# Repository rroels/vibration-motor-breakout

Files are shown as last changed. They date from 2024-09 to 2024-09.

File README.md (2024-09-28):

# 2-in-1 Vibration Motor Breakout Board

> [!WARNING]
> The information and material (code, designs, files, ...) are provided "AS IS". We make no representation or warranty of any kind, express or implied, regarding the accuracy, adequacy, validity, reliability, availability, or completeness of any information or material. Use this at your own risk.

> [!WARNING]
> At the time of writing this PCB has not even been produced yet, and as such, it has not even been tested yet! Once it has been properly tested, I will confirm that everything works as expected.

## Introduction

This is a breakout board for small vibration motors, such as those used in (smart)watches.

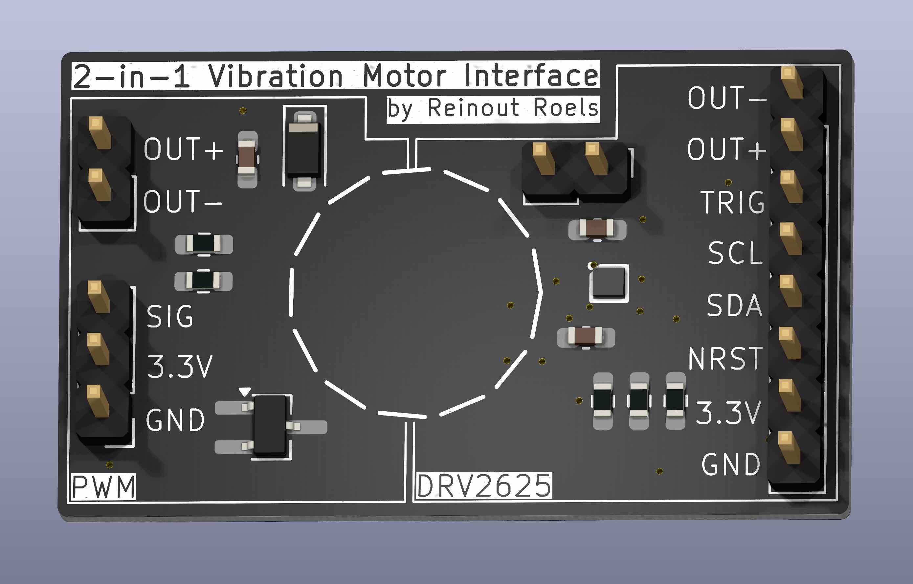
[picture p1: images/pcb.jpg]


It is 2-in-1, because it provides two ways to interface with the motor:

* via PWM
* via the Texas Instruments DRV2625 Haptic Driver IC

## Change Log

* v1.0
  * Initial design 

## Design Considerations

* NRST is not connected to the chip, as I was not able to route the NRST pin out of the tiny BGA footprint. This is however an optional feature anyway. 

## Schematics 

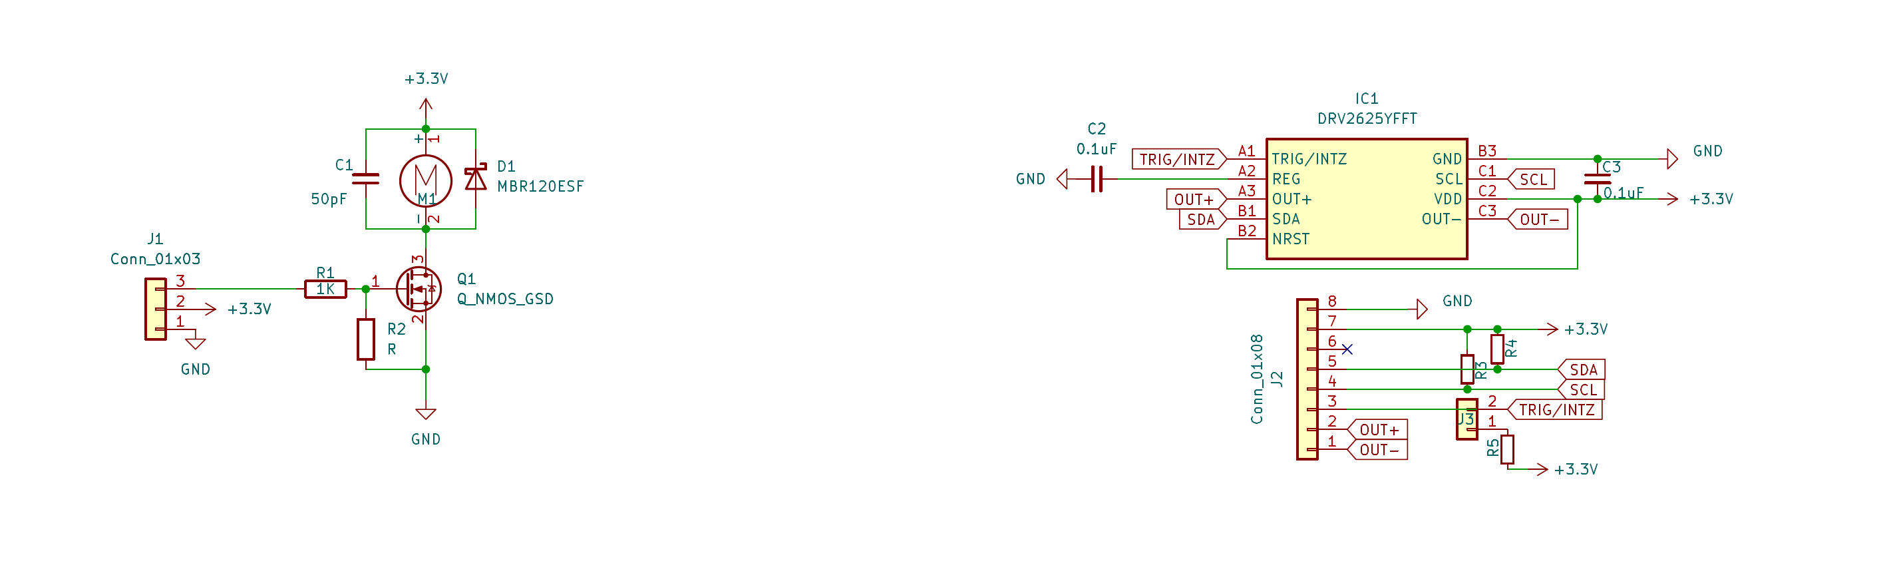
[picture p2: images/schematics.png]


## How to Obtain the Physical PCB



The Gerber file is in this repository (`kicad/gerber/vibration-motor.zip`). Simply upload this file a PCB manufacturer of your choice (JLPCB, PCBWay, ...), and you they will make it for you for as low as \$5 for 5 pieces (with the cheapest shipping option, which can take a few weeks).

For JLCPCB, select the order number option where they will replace "JLCJLCJLCJLC" on the board with the actual order number.

> [!WARNING]
> Note that will still have to solder the components onto the PCB yourself!

## How to Edit Design

Everything you need to edit this design in KiCad 8 is included in the repository.

However, this project uses symbols, footprints and 3D models from [Component Search Engine](https://componentsearchengine.com/). Their license allows us to do pretty much whatever we want with them, except redistributing them. For this reason I can't include them in this repository.

If you would like to edit the design yourself, you will need to download the following component libraries from [https://componentsearchengine.com/](https://componentsearchengine.com/) (it's free!):

* [https://componentsearchengine.com/part-view/DRV2625YFFT/Texas%20Instruments](https://componentsearchengine.com/part-view/DRV2625YFFT/Texas%20Instruments)

From the downloaded zip files, move the content of the `KiCad` and `3D` subfolders into the project structure, so that the end-result looks like this:

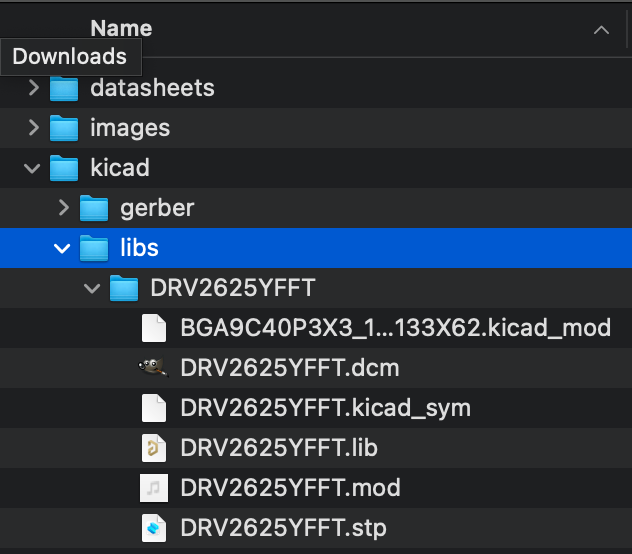
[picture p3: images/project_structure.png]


The KiCad project is configured to look for these files in these locations, using relative paths, so no changes to the project itself are required.	

## Sources

* [https://www.nordicsemi.com/Products/nPM1300](https://www.nordicsemi.com/Products/nPM1300)
* [https://docs.nordicsemi.com/category/npm1300-category](https://docs.nordicsemi.com/category/npm1300-category)
* [https://shop.pimoroni.com/products/drv2605l-linear-actuator-haptic-breakout](https://shop.pimoroni.com/products/drv2605l-linear-actuator-haptic-breakout)
* [https://hackaday.io/project/169967-nrf52-smartwatch](https://hackaday.io/project/169967-nrf52-smartwatch)
* [https://github.com/sqfmi/watchy-hardware/blob/v3.0/WatchySchematic.pdf](https://github.com/sqfmi/watchy-hardware/blob/v3.0/WatchySchematic.pdf)
* [https://www.hobbyelectronica.nl/product/tril-vibratie-dc-motor-module-v3-7-5-3/](https://www.hobbyelectronica.nl/product/tril-vibratie-dc-motor-module-v3-7-5-3/)
* [https://www.ineedmotors.com/news/how-to-build-a-vibration-motor-circuit-34060799.html](https://www.ineedmotors.com/news/how-to-build-a-vibration-motor-circuit-34060799.html)
* [https://www.precisionmicrodrives.com/ab-001-discrete-driver-circuits-for-vibration-motors](https://www.precisionmicrodrives.com/ab-001-discrete-driver-circuits-for-vibration-motors)

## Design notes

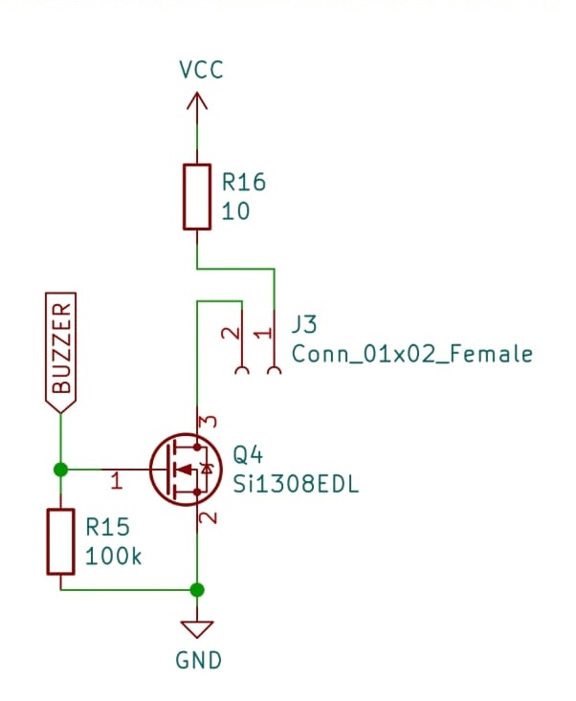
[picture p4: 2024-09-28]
images/nrf52_smartwatch.jpg

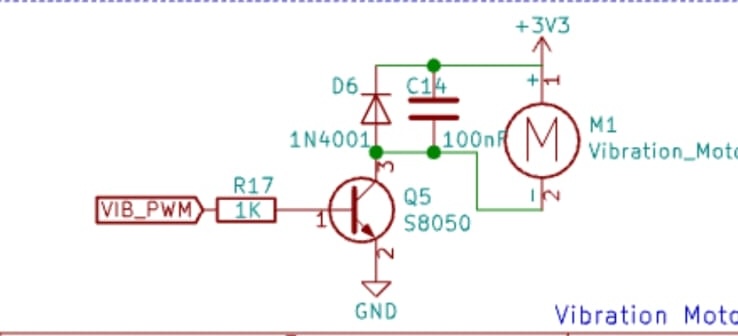
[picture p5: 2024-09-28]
images/watchy.jpg

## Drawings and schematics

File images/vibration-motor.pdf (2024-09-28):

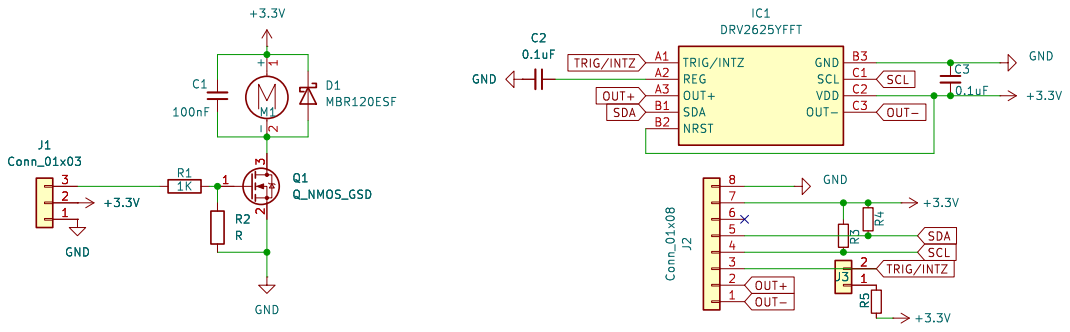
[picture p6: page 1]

Id: 1/1 Title: File: vibration-motor.kicad_sch Sheet: /

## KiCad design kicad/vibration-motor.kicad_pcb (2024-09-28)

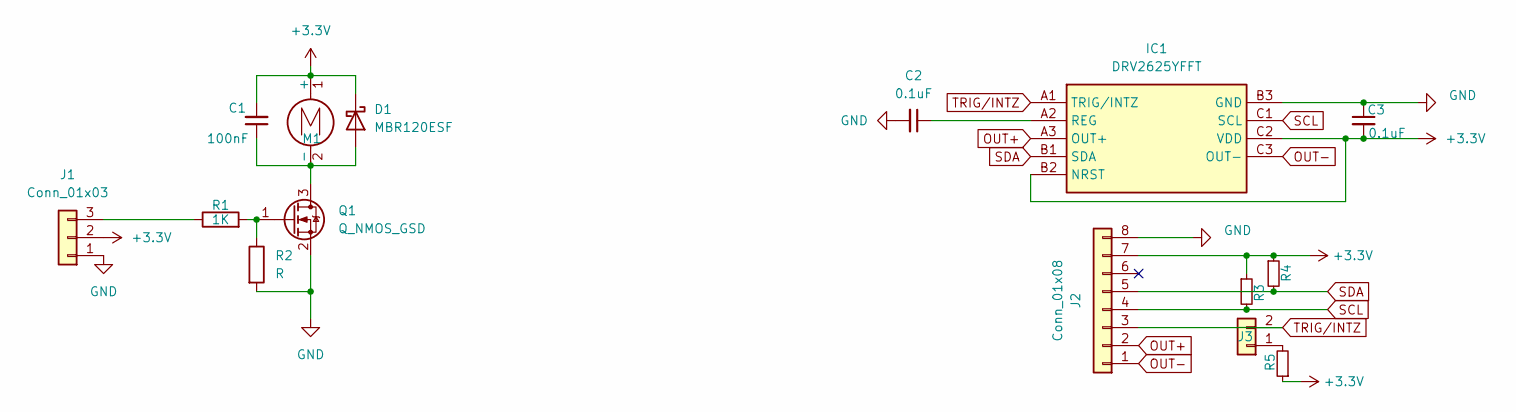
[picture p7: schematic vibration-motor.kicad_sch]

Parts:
C1: 100nF; C_0603_1608Metric_Pad1.08x0.95mm_HandSolder
C2, C3: 0.1uF; C_0603_1608Metric_Pad1.08x0.95mm_HandSolder
D1: MBR120ESF; D_SOD-123F
IC1: DRV2625YFFT; BGA9C40P3X3_147X133X62; Manufacturer_Part_Number DRV2625YFFT; Mouser Part Number 595-DRV2625YFFT
J1: Conn_01x03; PinHeader_1x03_P2.54mm_Vertical
J2: Conn_01x08; PinHeader_1x08_P2.54mm_Vertical
J3: Conn_01x02; PinHeader_1x02_P2.54mm_Vertical
M1: Motor_DC; PinHeader_1x02_P2.54mm_Vertical
Q1: Q_NMOS_GSD; TSOT-23_HandSoldering
R1: 1K; R_0603_1608Metric_Pad0.98x0.95mm_HandSolder
R2: R; R_0603_1608Metric_Pad0.98x0.95mm_HandSolder
R3, R4, R5: R_Small; R_0603_1608Metric_Pad0.98x0.95mm_HandSolder

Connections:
+3.3V: C1.2, C3.2, D1.1 (K), IC1.B2 (NRST), IC1.C2 (VDD), J1.2, J2.7, M1.1 (+), R3.1, R4.1, R5.1
GND: C2.2, C3.1, IC1.B3 (GND), J1.1, J2.8, Q1.2 (S), R2.2
unnamed: C1.1, D1.2 (A), M1.2 (-), Q1.3 (D)
unnamed: C2.1, IC1.A2 (REG)
unnamed: J1.3, R1.1
unnamed: J3.1, R5.2
unnamed: Q1.1 (G), R1.2, R2.1
OUT+: IC1.A3 (OUT+), J2.2
OUT-: IC1.C3 (OUT-), J2.1
SCL: IC1.C1 (SCL), J2.4, R3.2
SDA: IC1.B1 (SDA), J2.5, R4.2
TRIG/INTZ: IC1.A1 (TRIG/INTZ), J2.3, J3.2

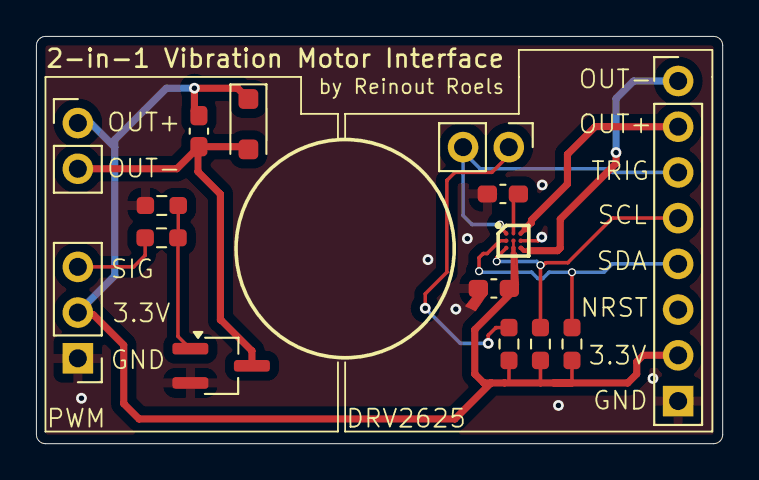
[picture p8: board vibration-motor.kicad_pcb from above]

Board: 2 copper layers, 38.1 x 22.6 mm, 15 parts (0 on the bottom side), 12 nets.
